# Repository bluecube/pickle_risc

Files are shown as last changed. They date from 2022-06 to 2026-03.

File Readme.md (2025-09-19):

# Pickle RISC 16bit CPU

... so I would like to build a computer, this time a little closer to "from scratch".

## Goals
- Fun!
- Aiming for a poorly defined balance between "easy to build" and "not too slow"
- Can run a multitasking OS
- Serve web site about itself (like Magic-1 does)
- Serial console interface
- Run at ~2MHz clock
    - 4MHz as a stretch goal :)
- Most instruction single cycle
- Probably RPi as a peripherial device, emulating a [GPU](notes/graphics.md), network card, storage, serial terminal...

## State
- Instruction set
    - Kind of done, still being tweaked to match the HW limitations and to improve proramming experience
- HW design
    - Slightly more than a fuzzy idea of how stuff should should go together
    - The block diagram shows most of the general idea
    - There is a [design document](design.md) that contains some (incomplete) information
- SW
    - Skeleton of a toolchain written in Rust ([toolchain-rs/](toolchain-rs/))
    - [Lisp](notes/lisp.md) interpreter is planned as a shell
        - Probably loosely based on [Make a Lisp](https://github.com/kanaka/mal/blob/master/process/guide.md)
        - Compiler as a stretch goal

## Links
### Inspiration
- Magic-1: http://www.homebrewcpu.com/
    - Showed me that there is so much magic in this topic.
    - I would like my machine to look like Magic-1 and do the stuff that Magic-1 does.
- Ben Eater's breadboard computer: https://www.youtube.com/playlist?list=PLowKtXNTBypGqImE405J2565dvjafglHU
    - Gave me the idea that I could actually build something like this.
- James Sharman's JAM-1: https://www.youtube.com/c/weirdboyjim/videos
    - Different goals, but just plain awesome :)

### Instruction set
- ARM Thumb Instruction set
- AVR instruction set

### Peripherials
- Interfacing SDHC card to 6502: https://github.com/gfoot/sdcard6502

### The rest
- MUPS/16, a nice 16bit CPU with similar goals/design: http://mups16.net/pages/overview.html#overview
- RISC-V: https://riscv.org/wp-content/uploads/2017/05/riscv-spec-v2.2.pdf
- Simple almost C-like language: https://incoherency.co.uk/blog/stories/slang.html
- Logisim evolution
- Nandgame ALU https://nandgame.com/
    > The ALU (Arithmetic/Logic Unit) performs one or more operations on two input values X and Y.
    >
    > The six flags select what operations to perform. Each flag trigger an operation when the flag is 1:
    > zx	Use 0 for X
    > nx	Invert X
    > zy	Use 0 for Y
    > ny	Invert Y
    > f	selects an operation:
    > 0: output is X AND Y
    > 1: output is X + Y
    > no	Invert output
    >
    > The flags can be combined and the specified order is significant.
    >
    > For example, if both zx and nx is 1, then X is inverted 0.

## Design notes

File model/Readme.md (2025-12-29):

# Board-level model

The goal of this model is to simulate individual boards.
This is done primarily as a sort of an executable spec for the
kicad schematic designs, but also to simulate (either individual boards, or later full CPU).
This code is not intended to be synthesized.

Also the SystemVerilog module will likely be later used as a source for microcode ROMs.

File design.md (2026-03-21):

# Pickle RISC 16bit CPU

This document contains notes about the hardware design that didn't fit anywhere else.
As usual this is incomplete and slightly outdated.

## Basic design
- 16bit
- Microcoded
- Most instructions take only single clock cycle
    - Instructions with memory access take two
- word addressable memory only!
    - 8bit access emulated in SW, helper instructions
      - `pack` (build word from bytes)
      - `bcmp` (byte-wise compare)
      - `shr8` (shift right by 8 bits)
- 15 general purpose registers R1-R15
- r0 is hardware zero register
- Two stage pipeline
    - Decode, Execute
    - Fetching next instruction is done as part of execute
    - Delay slot after all branch and jump instructions
- Only one status bit: `C`arry
- Control registers (Needs work!)
    - CpuStatus
        - RW
        - Contains:
            - 1b interrupt enabled flag
            - 1b privileged mode flag
                - Controls if privileged instructions are enabled
            - 1b MMU enabled flag
                - If disabled, MMU maps program memory pages 1:1 to frames at the beginning of memory, data pages to frames from in upper half of memory.
            - 6b Context ID
                - Used as a part of virtual page address, equivalent to process ID (with &lt; 64 processes)
    - NextCpuStatus
        - RW
        - Saved CPU status after interrupt
        - New CPU status to be set with ctxsw
    - NextPc
        - RW
        - Saved PC after interrupt
        - New PC to jump to with `ctxsw`
    - IntCause
        - RO
        - Bitmask of interrupt flags (!?!?!?!?)
    - MMUAddr: Virtual page address
        - RW
        - for storing MMU records
        - set during page failure
    - MMUData
        - WO
        - triggers the MMU write at given MMUAddr
    - Display
        - WO
        - Drives a 7-segment display on the front panel
        - 1:1 bit to segment mapping (= no decoder, must be done in SW)
- Separate virtual address spaces for data / code
    - To acces code from a process, the OS must map the memory as data
    - Exception is the ldp (load from program memory) instruction that allows each process to read its program space freely
- Interrupts
- System instructions:
    - `syscall`
        - Causes software interrupt
        - pass immediate value into `IntCause`
            - Quickly distinguish what's necessary in interrupt handler
                - syscall, vs IPC call, vs breakpoint, ...
    - `break`
        - Stop emulator
        - Switch physical CPU into single step mode
            - must be enabled by a physical switch?

## Instruction set weirdness
Compromises have been made :)

- No jumps with immediate values
  - This saves encoding space, but mostly allows us to fetch next instruction after jump without adder delay and without adding another address adder to a different stage.
  - Near jumps can be done in two cycles using `ldpc` (load program counter with offset) and then absolute jump.
  - Tight loops will benefit from preloading jump targets to a register.
- The architecture has something of a "zero page" with faster access
  - Globals within first 256B of memory can be accessed using just `ldi` for address load
    - `ldi addr, 0x17; ld dest, addr + 0`
  - Same for functions -- jumps to first 256 bytes are as fast as relative jumps
    - `ldi addr, 0xa5; jal r0, addr`
- No pop
  - Pop requires two registers to be written.
  - Repeated pops (eg. restoring state after interrupt) can be worked around by batching `ld` with offset followed by a single add. (`ld r1, sp; ld r2,sp+1; ld r3, sp+2; addi sp, sp, 3`)
- `stinc` instead of push
  - This is strictly stronger than push (`push sp, v` = `stinc sp-1, v`)
  - Not sure if arguments other than +-1 are useful, but this instruction is just "we can do it for (almost) free, so why not".
- On wishlist -- slightly weird, but potentially useful:
    - Microcoded multi cycle `memcpy` instruction
      - Probably could run in 2 * N + 1 cycles to copy N words of memory, that's as fast as a dedicated DMA device could run
      - Dedicated DMA would also need to block the CPU (because instruction fetches)
    - Three cycle long atomic swap memory and register instruction
      - Not strictly necessary, because OS can do atomic operations through a syscall, but this would allow us to play with fast futex implementations.

## Microcode ROM
### Incoming signals
(goal is 13 (= 8k ROM), or 15 (= 32k ROM))
- 8 bits from instruction
- 1 bit interrupt pending
- 1 bit kernel mode
- 2 bits condition flags
    - ALU A is zero
    - C
- 2 bits Microcode FSM state

Total 14

### Outgoing control lines
(goal is as small as possible multiple of 8; needs more work)

TODO

- 2 bits Microcode FSM next state

## Memory
- 16 bit-addressable memory (Byte level access emulated in SW)
- Separate data and program segments
- Virtual address format: `CC CCCC S AAAA AA | AA AAAA AAAA`
    - `C` - 6bit context ID (from control register)
    - `S` - segment (0 = data segment, 1 = program segment)
    - `A` - 16bit address
- MMU
    - Built out of two 8k * 8b SRAM ICs
    - Record format: `RWFF FFFF FFFF FFFF`
        - `R` - Read allowed
        - `W` - Write allowed
        - `F` - Frame address (14b)
    - Software page fault handling
        - raises interrupt on access violation
    - 10b page size -> 1kWord = 2kB pages
    - 24b physical address -> 16MWord physical address space
        - 22bit ROM address space
            - 8kWords used (pair of 8k * 8b ROM chips)
        - 22bit device address space
        - 23bit RAM address space
            - max 8MWord = 16MB RAM

## Peripherials wishlist
- UART
- RTC
- Storage
    - SD card using SPI interface?
- [Graphics](notes/graphics.md)
- Network card
    - Probably using the Raspbery PI board (same as with the graphics)
    - W5500 module?
- Hardware multiplier card
    - 16b x 16b -> 32b
    - memory mapped
    - https://www.youtube.com/watch?v=M8dk0JpkrbY

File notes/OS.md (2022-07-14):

# OS
Pickle risc will run a multitasking OS.

## Design

Microkernels are cool.

### Functionatity in kernel
- Scheduler
- IPC
    - Message passing
        - Synchronous
            - Blocking and non-blocking mode
            - Small fixed payload
                - Registers only?
    - Shared memory
        - `sharemem`
            - "Share this page of my memory to that process"
            - returns some sort of ID uniquely identifying the share
        - `mmap` can take the ID from previous step to map the memory

- Memory / paging

### Functionality in servers
- UART driver
- Disk driver
- Filesystem
- Timer
- Networking
- Synchronization & locking

### Semaphores & locking
- Process can only block on message sending / receiving
- Mutex impl -- a little like futex in Linux
    - Atomic variable
        - 0: unlocked
        - 1: locked, noone is waiting
        - >=2 : locked, waiting processes
    - Sends message to synchronization server
        - Block on this
            - How is the lock object identified?
                - the sync server should not need (privileged) access to memory mappings
                - Lock objects carries ID inside?

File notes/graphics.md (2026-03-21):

# Graphics

While the CPU's main focus is to be a multi-user system mainly focused on networking (like Magic-1!),
I'd also like to have at least some fancy graphics.
But I definitely don't want to implement a VGA graphics from discrete logic.

Right now there are two separate options:
1. RPi based GPU, connected over SPI to the CPU memory bus.
2. Network based graphics protocol, display server on a "real" computer.

Both of the options would provide basically the same functionality.

## Goals
- High-ish resolution
- GUI system similar to Windows 3.0 can be built on top of it
- Fast enough for GUI and simple games
    - Even when running over low bandwidth SLIP link

# Design
- 640x480 or 800x600
- 4bpp or 8bpp, 16b palette entries (RGB565)
- Graphics memory
    - 512kB video RAM (TODO: 1MB?)
- Selectable framebuffer offset and row stride
    - Can be used to double buffer and/or scroll the display
- Commands:
    - Upload to graphics memory
    - Blit
        with or without transparent color
    - Draw primitives in graphics memory
        - Axis aligned rectangle
            - filled
            - outlined
        - Line
        - Filled triangle
- Events:
    - Keyboard
    - Mouse
    - Joystick?
- Maybe we could also support sound?
- Emulation details
  - Blitter runs on 2-4MPx/s
  - Emulates scanlines

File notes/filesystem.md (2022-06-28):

# Filesystem notes
These are just quick notes about how I'd like to implement the filesystem,
based only on assumptions on how the storage will work.
No real work has been done on this.

This assumes that we will have something like an SD card connected through SPI.

## Goals
- Simple (will be implemented in assembler)
    - Specifically: Not COW :-)
- Fun!

## Design
- Block size 1kWord = 2kB
    - Matches the MMU page size
- 16b block pointers
- => 128MB max addressable space

### Superblock
- First block of the device
- "PICKLEFS" magic
- Parameters?
- 16b Pointer to first unused block
- 16b Pointer to root directory

### Boot area
- Optional?
- Contiguous range of blocks starting at the second block of the device
- Must have a corresponding directory entry and file header

### Unused blocks
- 16b pointer to next unused block

### Root directory
- `..` entry points to itself
- Otherwise like normal directory

### Directory
- Creation date
    - ?
- Flags
    - ?
- 16b refcount
- List of entries
    - Name
        - Length?
        - Format?
    - 16b pointer to first block of entry (either file header or directory)
- 16b pointer to next block of directory
- Special entry
    - `..` pointing to parent
- Additional directory blocks only contain the entry list and next pointer

### File header
- Creation date
    - ?
- Flags
    - ?
- 16b refcount
- Size in B
    - 32b?
- List of 16b data block pointers
    - Number of valid blocks can be calculated from file size
- 16b pointer to next block of file header
- Additional file header blocks only contain the block pointer list and next pointer

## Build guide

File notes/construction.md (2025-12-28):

# CPU Mechanical & Electrical Construction

- Eurocard (3U, 100x160mm)
- 96 pin connector
- Backplane split into two zones
  - Core zone:
    - CPU internal cards (register decoder, register slices, ALU, instruction decoder, ...).
    - Each backplane slot has potentially different pinout
    - 3D printed keys enforcing correct card placement?
  - Memory / peripherial zone
    - All pinouts identical
- "Tiled" backplane?
  - Individual pieces of backplane connected together using edge connectors
  - To simplify development, make cheaper fails
- Clock
  - Selectable speed main clock (>=10MHz max speed)
    - 20MHz oscillator piped into 74HC193
    - DIP switch controling the frequency
    - Second counter chip for clock assymetry?
  - Single step mode (buttons: Stop, Step, Run)
  - Break function
    - If enabled by a HW switch, goes into single step mode.
    - Interrupt if break signal arrives and break is disabled
  - Sleep mode (clock is ignored until an interrupt arrives)

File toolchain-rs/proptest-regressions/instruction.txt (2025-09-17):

# Seeds for failure cases proptest has generated in the past. It is
# automatically read and these particular cases re-run before any
# novel cases are generated.
#
# It is recommended to check this file in to source control so that
# everyone who runs the test benefits from these saved cases.
cc 9dc10df642abab5001a11f73752e9213c0fbb279a0ac84b5d1df86588d58f470 # shrinks to input = _InstructionWordRoundtripArgs { instr: Add { rd: Reg(u4(0)), ra: Reg(u4(8)), rb: Reg(u4(0)) } }
cc bcaa2e5ca4c8241c8ef2832069ae7a77c72e44657debe7e9c622a8bcb71ae072 # shrinks to input = _InstructionWordRoundtripArgs { instr: Bc { offset: -1 } }
cc d3591c18287fcd63b3d7897a659aaecbf9b31d5293ab9dd24c8d99ab523e4f6f # shrinks to input = _InstructionWordRoundtripArgs { instr: Bnc { offset: 0 } }
cc fd1b72449b7ee29276ebb02a0e1c3fad55f5e9b69171cacf9a00b8df15d9bed2 # shrinks to input = _InstructionWordRoundtripArgs { instr: Addi { rd: Reg(u4(0)), v: 1 } }
cc 28ca0e33b48f58821ffe0bdb45a0052da90d4b49a57a24e807921635d42b3c66 # shrinks to input = _InstructionWordRoundtripArgs { instr: Syscall { val: u4(0) } }
cc 16a8a451fe999dba209733c277c157544f69e01f3e4dd4225c0b32ed40378362 # shrinks to input = _RegBadU16Args { num: 8 }

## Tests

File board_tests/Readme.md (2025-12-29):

# Python tests for boards

Plan here is to have one set of python tests per board, ideally completely testing the behavior.

The tests can then be executed against the [verilog model](../model), or against real hardware
using the board tester (TBD).

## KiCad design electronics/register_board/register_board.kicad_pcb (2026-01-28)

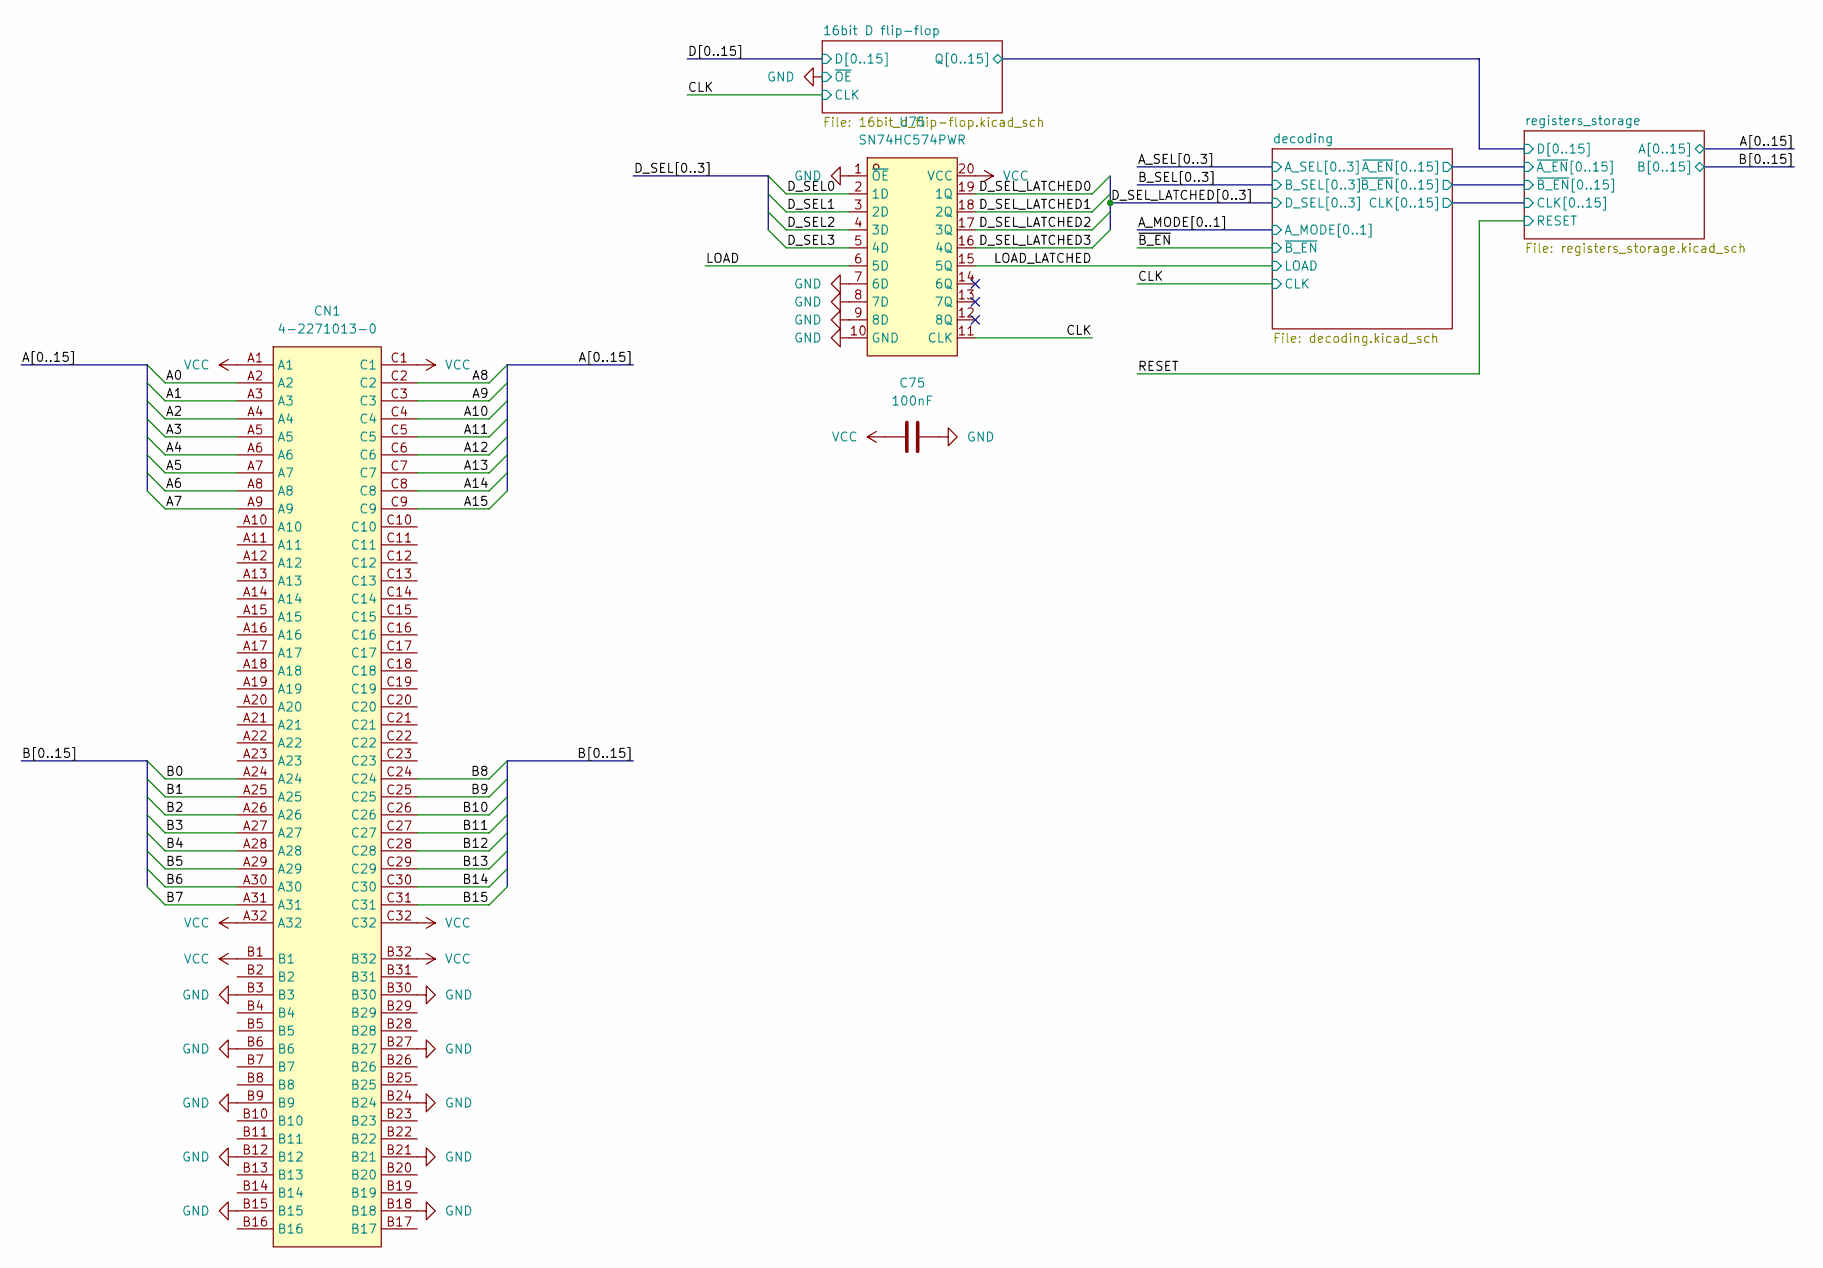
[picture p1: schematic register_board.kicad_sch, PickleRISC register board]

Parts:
C75: 100nF; C_0603_1608Metric
CN1: 4-2271013-0; CONN-TH_96P-P2.54_4-2271013-0; LCSC Part C442617
U75: SN74HC574PWR; TSSOP-20_L6.5-W4.4-P0.65-LS6.4-BL; LCSC Part C132111

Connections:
/A0: CN1.A2; also elsewhere on the board
/A1: CN1.A3; also elsewhere on the board
/A2: CN1.A4; also elsewhere on the board
/A3: CN1.A5; also elsewhere on the board
/A4: CN1.A6; also elsewhere on the board
/A5: CN1.A7; also elsewhere on the board
/A6: CN1.A8; also elsewhere on the board
/A7: CN1.A9; also elsewhere on the board
/A8: CN1.C2; also elsewhere on the board
/A9: CN1.C3; also elsewhere on the board
/A10: CN1.C4; also elsewhere on the board
/A11: CN1.C5; also elsewhere on the board
/A12: CN1.C6; also elsewhere on the board
/A13: CN1.C7; also elsewhere on the board
/A14: CN1.C8; also elsewhere on the board
/A15: CN1.C9; also elsewhere on the board
/B0: CN1.A24; also elsewhere on the board
/B1: CN1.A25; also elsewhere on the board
/B2: CN1.A26; also elsewhere on the board
/B3: CN1.A27; also elsewhere on the board
/B4: CN1.A28; also elsewhere on the board
/B5: CN1.A29; also elsewhere on the board
/B6: CN1.A30; also elsewhere on the board
/B7: CN1.A31; also elsewhere on the board
/B8: CN1.C24; also elsewhere on the board
/B9: CN1.C25; also elsewhere on the board
/B10: CN1.C26; also elsewhere on the board
/B11: CN1.C27; also elsewhere on the board
/B12: CN1.C28; also elsewhere on the board
/B13: CN1.C29; also elsewhere on the board
/B14: CN1.C30; also elsewhere on the board
/B15: CN1.C31; also elsewhere on the board
/CLK: U75.11 (CLK); also elsewhere on the board
/D_SEL0: U75.2 (1D)
/D_SEL1: U75.3 (2D)
/D_SEL2: U75.4 (3D)
/D_SEL3: U75.5 (4D)
/D_SEL_LATCHED0: U75.19 (1Q); also elsewhere on the board
/D_SEL_LATCHED1: U75.18 (2Q); also elsewhere on the board
/D_SEL_LATCHED2: U75.17 (3Q); also elsewhere on the board
/D_SEL_LATCHED3: U75.16 (4Q); also elsewhere on the board
/LOAD: U75.6 (5D)
/LOAD_LATCHED: U75.15 (5Q); also elsewhere on the board
GND: C75.2, CN1.B3, CN1.B6, CN1.B9, CN1.B12, CN1.B15, CN1.B18, CN1.B21, CN1.B24, CN1.B27, CN1.B30, U75.1 (~OE), U75.7 (6D), U75.8 (7D), U75.9 (8D), U75.10 (GND); also elsewhere on the board
VCC: C75.1, CN1.A1, CN1.A32, CN1.B1, CN1.B32, CN1.C1, CN1.C32, U75.20 (VCC); also elsewhere on the board

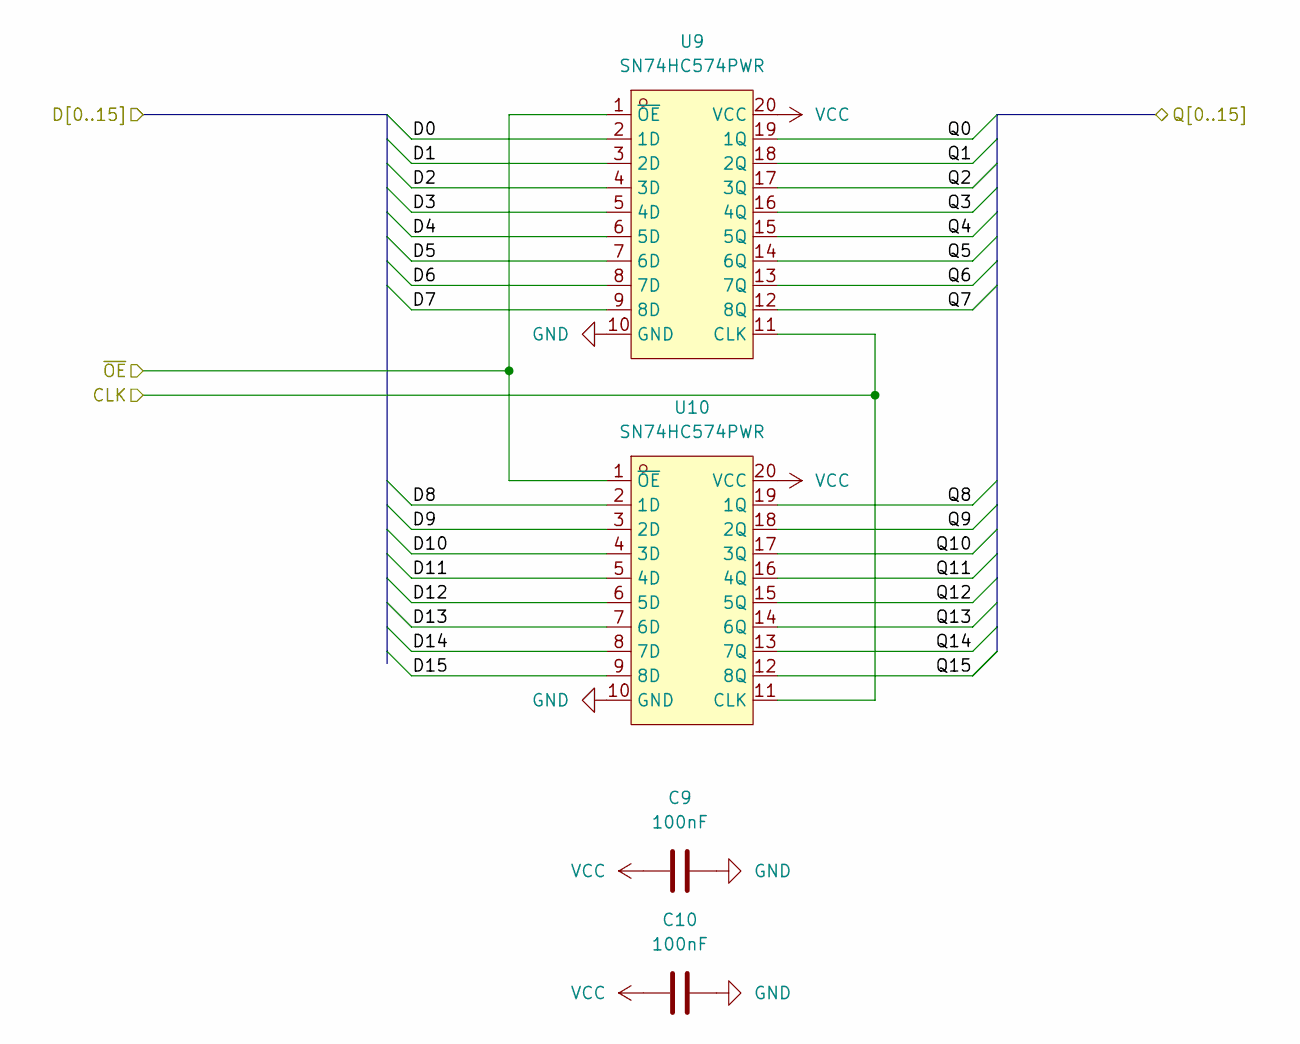
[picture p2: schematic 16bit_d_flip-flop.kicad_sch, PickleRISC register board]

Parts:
C9, C10: 100nF; C_0603_1608Metric
U9, U10: SN74HC574PWR; TSSOP-20_L6.5-W4.4-P0.65-LS6.4-BL; LCSC Part C132111

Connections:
/CLK: U9.11 (CLK), U10.11 (CLK); also elsewhere on the board
/D0: U9.2 (1D)
/D1: U9.3 (2D)
/D2: U9.4 (3D)
/D3: U9.5 (4D)
/D4: U9.6 (5D)
/D5: U9.7 (6D)
/D6: U9.8 (7D)
/D7: U9.9 (8D)
/D8: U10.2 (1D)
/D9: U10.3 (2D)
/D10: U10.4 (3D)
/D11: U10.5 (4D)
/D12: U10.6 (5D)
/D13: U10.7 (6D)
/D14: U10.8 (7D)
/D15: U10.9 (8D)
/registers_storage/D0: U9.19 (1Q); also elsewhere on the board
/registers_storage/D1: U9.18 (2Q); also elsewhere on the board
/registers_storage/D2: U9.17 (3Q); also elsewhere on the board
/registers_storage/D3: U9.16 (4Q); also elsewhere on the board
/registers_storage/D4: U9.15 (5Q); also elsewhere on the board
/registers_storage/D5: U9.14 (6Q); also elsewhere on the board
/registers_storage/D6: U9.13 (7Q); also elsewhere on the board
/registers_storage/D7: U9.12 (8Q); also elsewhere on the board
/registers_storage/D8: U10.19 (1Q); also elsewhere on the board
/registers_storage/D9: U10.18 (2Q); also elsewhere on the board
/registers_storage/D10: U10.17 (3Q); also elsewhere on the board
/registers_storage/D11: U10.16 (4Q); also elsewhere on the board
/registers_storage/D12: U10.15 (5Q); also elsewhere on the board
/registers_storage/D13: U10.14 (6Q); also elsewhere on the board
/registers_storage/D14: U10.13 (7Q); also elsewhere on the board
/registers_storage/D15: U10.12 (8Q); also elsewhere on the board
GND: C9.2, C10.2, U9.1 (~OE), U9.10 (GND), U10.1 (~OE), U10.10 (GND); also elsewhere on the board
VCC: C9.1, C10.1, U9.20 (VCC), U10.20 (VCC); also elsewhere on the board

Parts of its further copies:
C15, C16, C17, C18, C19, C20, C21, C22, C23, C24, C25, C26, C27, C28, C29, C30, C31, C32, C33, C34, C35, C36, C37, C38, C39, C40, C41, C42, C43, C44, C45, C46, C47, C48, C49, C50, C51, C52, C53, C54, C55, C56, C57, C58, C59, C60, C61, C62, C63, C64, C65, C66, C67, C68, C69, C70, C71, C72, C73, C74: 100nF; C_0603_1608Metric
U15, U16, U17, U18, U19, U20, U21, U22, U23, U24, U25, U26, U27, U28, U29, U30, U31, U32, U33, U34, U35, U36, U37, U38, U39, U40, U41, U42, U43, U44, U45, U46, U47, U48, U49, U50, U51, U52, U53, U54, U55, U56, U57, U58, U59, U60, U61, U62, U63, U64, U65, U66, U67, U68, U69, U70, U71, U72, U73, U74: SN74HC574PWR; TSSOP-20_L6.5-W4.4-P0.65-LS6.4-BL; LCSC Part C132111

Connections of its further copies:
/A0: U15.19 (1Q), U19.19 (1Q), U23.19 (1Q), U27.19 (1Q), U31.19 (1Q), U35.19 (1Q), U39.19 (1Q), U43.19 (1Q), U47.19 (1Q), U51.19 (1Q), U55.19 (1Q), U59.19 (1Q), U63.19 (1Q), U67.19 (1Q), U71.19 (1Q); also elsewhere on the board
/A1: U15.18 (2Q), U19.18 (2Q), U23.18 (2Q), U27.18 (2Q), U31.18 (2Q), U35.18 (2Q), U39.18 (2Q), U43.18 (2Q), U47.18 (2Q), U51.18 (2Q), U55.18 (2Q), U59.18 (2Q), U63.18 (2Q), U67.18 (2Q), U71.18 (2Q); also elsewhere on the board
/A2: U15.17 (3Q), U19.17 (3Q), U23.17 (3Q), U27.17 (3Q), U31.17 (3Q), U35.17 (3Q), U39.17 (3Q), U43.17 (3Q), U47.17 (3Q), U51.17 (3Q), U55.17 (3Q), U59.17 (3Q), U63.17 (3Q), U67.17 (3Q), U71.17 (3Q); also elsewhere on the board
/A3: U15.16 (4Q), U19.16 (4Q), U23.16 (4Q), U27.16 (4Q), U31.16 (4Q), U35.16 (4Q), U39.16 (4Q), U43.16 (4Q), U47.16 (4Q), U51.16 (4Q), U55.16 (4Q), U59.16 (4Q), U63.16 (4Q), U67.16 (4Q), U71.16 (4Q); also elsewhere on the board
/A4: U15.15 (5Q), U19.15 (5Q), U23.15 (5Q), U27.15 (5Q), U31.15 (5Q), U35.15 (5Q), U39.15 (5Q), U43.15 (5Q), U47.15 (5Q), U51.15 (5Q), U55.15 (5Q), U59.15 (5Q), U63.15 (5Q), U67.15 (5Q), U71.15 (5Q); also elsewhere on the board
/A5: U15.14 (6Q), U19.14 (6Q), U23.14 (6Q), U27.14 (6Q), U31.14 (6Q), U35.14 (6Q), U39.14 (6Q), U43.14 (6Q), U47.14 (6Q), U51.14 (6Q), U55.14 (6Q), U59.14 (6Q), U63.14 (6Q), U67.14 (6Q), U71.14 (6Q); also elsewhere on the board
/A6: U15.13 (7Q), U19.13 (7Q), U23.13 (7Q), U27.13 (7Q), U31.13 (7Q), U35.13 (7Q), U39.13 (7Q), U43.13 (7Q), U47.13 (7Q), U51.13 (7Q), U55.13 (7Q), U59.13 (7Q), U63.13 (7Q), U67.13 (7Q), U71.13 (7Q); also elsewhere on the board
/A7: U15.12 (8Q), U19.12 (8Q), U23.12 (8Q), U27.12 (8Q), U31.12 (8Q), U35.12 (8Q), U39.12 (8Q), U43.12 (8Q), U47.12 (8Q), U51.12 (8Q), U55.12 (8Q), U59.12 (8Q), U63.12 (8Q), U67.12 (8Q), U71.12 (8Q); also elsewhere on the board
/A8: U16.19 (1Q), U20.19 (1Q), U24.19 (1Q), U28.19 (1Q), U32.19 (1Q), U36.19 (1Q), U40.19 (1Q), U44.19 (1Q), U48.19 (1Q), U52.19 (1Q), U56.19 (1Q), U60.19 (1Q), U64.19 (1Q), U68.19 (1Q), U72.19 (1Q); also elsewhere on the board
/A9: U16.18 (2Q), U20.18 (2Q), U24.18 (2Q), U28.18 (2Q), U32.18 (2Q), U36.18 (2Q), U40.18 (2Q), U44.18 (2Q), U48.18 (2Q), U52.18 (2Q), U56.18 (2Q), U60.18 (2Q), U64.18 (2Q), U68.18 (2Q), U72.18 (2Q); also elsewhere on the board
/A10: U16.17 (3Q), U20.17 (3Q), U24.17 (3Q), U28.17 (3Q), U32.17 (3Q), U36.17 (3Q), U40.17 (3Q), U44.17 (3Q), U48.17 (3Q), U52.17 (3Q), U56.17 (3Q), U60.17 (3Q), U64.17 (3Q), U68.17 (3Q), U72.17 (3Q); also elsewhere on the board
/A11: U16.16 (4Q), U20.16 (4Q), U24.16 (4Q), U28.16 (4Q), U32.16 (4Q), U36.16 (4Q), U40.16 (4Q), U44.16 (4Q), U48.16 (4Q), U52.16 (4Q), U56.16 (4Q), U60.16 (4Q), U64.16 (4Q), U68.16 (4Q), U72.16 (4Q); also elsewhere on the board
/A12: U16.15 (5Q), U20.15 (5Q), U24.15 (5Q), U28.15 (5Q), U32.15 (5Q), U36.15 (5Q), U40.15 (5Q), U44.15 (5Q), U48.15 (5Q), U52.15 (5Q), U56.15 (5Q), U60.15 (5Q), U64.15 (5Q), U68.15 (5Q), U72.15 (5Q); also elsewhere on the board
/A13: U16.14 (6Q), U20.14 (6Q), U24.14 (6Q), U28.14 (6Q), U32.14 (6Q), U36.14 (6Q), U40.14 (6Q), U44.14 (6Q), U48.14 (6Q), U52.14 (6Q), U56.14 (6Q), U60.14 (6Q), U64.14 (6Q), U68.14 (6Q), U72.14 (6Q); also elsewhere on the board
/A14: U16.13 (7Q), U20.13 (7Q), U24.13 (7Q), U28.13 (7Q), U32.13 (7Q), U36.13 (7Q), U40.13 (7Q), U44.13 (7Q), U48.13 (7Q), U52.13 (7Q), U56.13 (7Q), U60.13 (7Q), U64.13 (7Q), U68.13 (7Q), U72.13 (7Q); also elsewhere on the board
/A15: U16.12 (8Q), U20.12 (8Q), U24.12 (8Q), U28.12 (8Q), U32.12 (8Q), U36.12 (8Q), U40.12 (8Q), U44.12 (8Q), U48.12 (8Q), U52.12 (8Q), U56.12 (8Q), U60.12 (8Q), U64.12 (8Q), U68.12 (8Q), U72.12 (8Q); also elsewhere on the board
/B0: U17.19 (1Q), U21.19 (1Q), U25.19 (1Q), U29.19 (1Q), U33.19 (1Q), U37.19 (1Q), U41.19 (1Q), U45.19 (1Q), U49.19 (1Q), U53.19 (1Q), U57.19 (1Q), U61.19 (1Q), U65.19 (1Q), U69.19 (1Q), U73.19 (1Q); also elsewhere on the board
/B1: U17.18 (2Q), U21.18 (2Q), U25.18 (2Q), U29.18 (2Q), U33.18 (2Q), U37.18 (2Q), U41.18 (2Q), U45.18 (2Q), U49.18 (2Q), U53.18 (2Q), U57.18 (2Q), U61.18 (2Q), U65.18 (2Q), U69.18 (2Q), U73.18 (2Q); also elsewhere on the board
/B2: U17.17 (3Q), U21.17 (3Q), U25.17 (3Q), U29.17 (3Q), U33.17 (3Q), U37.17 (3Q), U41.17 (3Q), U45.17 (3Q), U49.17 (3Q), U53.17 (3Q), U57.17 (3Q), U61.17 (3Q), U65.17 (3Q), U69.17 (3Q), U73.17 (3Q); also elsewhere on the board
/B3: U17.16 (4Q), U21.16 (4Q), U25.16 (4Q), U29.16 (4Q), U33.16 (4Q), U37.16 (4Q), U41.16 (4Q), U45.16 (4Q), U49.16 (4Q), U53.16 (4Q), U57.16 (4Q), U61.16 (4Q), U65.16 (4Q), U69.16 (4Q), U73.16 (4Q); also elsewhere on the board
/B4: U17.15 (5Q), U21.15 (5Q), U25.15 (5Q), U29.15 (5Q), U33.15 (5Q), U37.15 (5Q), U41.15 (5Q), U45.15 (5Q), U49.15 (5Q), U53.15 (5Q), U57.15 (5Q), U61.15 (5Q), U65.15 (5Q), U69.15 (5Q), U73.15 (5Q); also elsewhere on the board
/B5: U17.14 (6Q), U21.14 (6Q), U25.14 (6Q), U29.14 (6Q), U33.14 (6Q), U37.14 (6Q), U41.14 (6Q), U45.14 (6Q), U49.14 (6Q), U53.14 (6Q), U57.14 (6Q), U61.14 (6Q), U65.14 (6Q), U69.14 (6Q), U73.14 (6Q); also elsewhere on the board
/B6: U17.13 (7Q), U21.13 (7Q), U25.13 (7Q), U29.13 (7Q), U33.13 (7Q), U37.13 (7Q), U41.13 (7Q), U45.13 (7Q), U49.13 (7Q), U53.13 (7Q), U57.13 (7Q), U61.13 (7Q), U65.13 (7Q), U69.13 (7Q), U73.13 (7Q); also elsewhere on the board
/B7: U17.12 (8Q), U21.12 (8Q), U25.12 (8Q), U29.12 (8Q), U33.12 (8Q), U37.12 (8Q), U41.12 (8Q), U45.12 (8Q), U49.12 (8Q), U53.12 (8Q), U57.12 (8Q), U61.12 (8Q), U65.12 (8Q), U69.12 (8Q), U73.12 (8Q); also elsewhere on the board
/B8: U18.19 (1Q), U22.19 (1Q), U26.19 (1Q), U30.19 (1Q), U34.19 (1Q), U38.19 (1Q), U42.19 (1Q), U46.19 (1Q), U50.19 (1Q), U54.19 (1Q), U58.19 (1Q), U62.19 (1Q), U66.19 (1Q), U70.19 (1Q), U74.19 (1Q); also elsewhere on the board
/B9: U18.18 (2Q), U22.18 (2Q), U26.18 (2Q), U30.18 (2Q), U34.18 (2Q), U38.18 (2Q), U42.18 (2Q), U46.18 (2Q), U50.18 (2Q), U54.18 (2Q), U58.18 (2Q), U62.18 (2Q), U66.18 (2Q), U70.18 (2Q), U74.18 (2Q); also elsewhere on the board
/B10: U18.17 (3Q), U22.17 (3Q), U26.17 (3Q), U30.17 (3Q), U34.17 (3Q), U38.17 (3Q), U42.17 (3Q), U46.17 (3Q), U50.17 (3Q), U54.17 (3Q), U58.17 (3Q), U62.17 (3Q), U66.17 (3Q), U70.17 (3Q), U74.17 (3Q); also elsewhere on the board
/B11: U18.16 (4Q), U22.16 (4Q), U26.16 (4Q), U30.16 (4Q), U34.16 (4Q), U38.16 (4Q), U42.16 (4Q), U46.16 (4Q), U50.16 (4Q), U54.16 (4Q), U58.16 (4Q), U62.16 (4Q), U66.16 (4Q), U70.16 (4Q), U74.16 (4Q); also elsewhere on the board
/B12: U18.15 (5Q), U22.15 (5Q), U26.15 (5Q), U30.15 (5Q), U34.15 (5Q), U38.15 (5Q), U42.15 (5Q), U46.15 (5Q), U50.15 (5Q), U54.15 (5Q), U58.15 (5Q), U62.15 (5Q), U66.15 (5Q), U70.15 (5Q), U74.15 (5Q); also elsewhere on the board
/B13: U18.14 (6Q), U22.14 (6Q), U26.14 (6Q), U30.14 (6Q), U34.14 (6Q), U38.14 (6Q), U42.14 (6Q), U46.14 (6Q), U50.14 (6Q), U54.14 (6Q), U58.14 (6Q), U62.14 (6Q), U66.14 (6Q), U70.14 (6Q), U74.14 (6Q); also elsewhere on the board
/B14: U18.13 (7Q), U22.13 (7Q), U26.13 (7Q), U30.13 (7Q), U34.13 (7Q), U38.13 (7Q), U42.13 (7Q), U46.13 (7Q), U50.13 (7Q), U54.13 (7Q), U58.13 (7Q), U62.13 (7Q), U66.13 (7Q), U70.13 (7Q), U74.13 (7Q); also elsewhere on the board
/B15: U18.12 (8Q), U22.12 (8Q), U26.12 (8Q), U30.12 (8Q), U34.12 (8Q), U38.12 (8Q), U42.12 (8Q), U46.12 (8Q), U50.12 (8Q), U54.12 (8Q), U58.12 (8Q), U62.12 (8Q), U66.12 (8Q), U70.12 (8Q), U74.12 (8Q); also elsewhere on the board
/decoding/CLK1: U15.11 (CLK), U16.11 (CLK), U17.11 (CLK), U18.11 (CLK); also elsewhere on the board
/decoding/CLK2: U19.11 (CLK), U20.11 (CLK), U21.11 (CLK), U22.11 (CLK); also elsewhere on the board
/decoding/CLK3: U23.11 (CLK), U24.11 (CLK), U25.11 (CLK), U26.11 (CLK); also elsewhere on the board
/decoding/CLK4: U27.11 (CLK), U28.11 (CLK), U29.11 (CLK), U30.11 (CLK); also elsewhere on the board
/decoding/CLK5: U31.11 (CLK), U32.11 (CLK), U33.11 (CLK), U34.11 (CLK); also elsewhere on the board
/decoding/CLK6: U35.11 (CLK), U36.11 (CLK), U37.11 (CLK), U38.11 (CLK); also elsewhere on the board
/decoding/CLK7: U39.11 (CLK), U40.11 (CLK), U41.11 (CLK), U42.11 (CLK); also elsewhere on the board
/decoding/CLK8: U43.11 (CLK), U44.11 (CLK), U45.11 (CLK), U46.11 (CLK); also elsewhere on the board
/decoding/CLK9: U47.11 (CLK), U48.11 (CLK), U49.11 (CLK), U50.11 (CLK); also elsewhere on the board
/decoding/CLK10: U51.11 (CLK), U52.11 (CLK), U53.11 (CLK), U54.11 (CLK); also elsewhere on the board
/decoding/CLK11: U55.11 (CLK), U56.11 (CLK), U57.11 (CLK), U58.11 (CLK); also elsewhere on the board
/decoding/CLK12: U59.11 (CLK), U60.11 (CLK), U61.11 (CLK), U62.11 (CLK); also elsewhere on the board
/decoding/CLK13: U63.11 (CLK), U64.11 (CLK), U65.11 (CLK), U66.11 (CLK); also elsewhere on the board
/decoding/CLK14: U67.11 (CLK), U68.11 (CLK), U69.11 (CLK), U70.11 (CLK); also elsewhere on the board
/decoding/CLK15: U71.11 (CLK), U72.11 (CLK), U73.11 (CLK), U74.11 (CLK); also elsewhere on the board
/decoding/~A_EN1: U15.1 (~OE), U16.1 (~OE); also elsewhere on the board
/decoding/~A_EN2: U19.1 (~OE), U20.1 (~OE); also elsewhere on the board
/decoding/~A_EN3: U23.1 (~OE), U24.1 (~OE); also elsewhere on the board
/decoding/~A_EN4: U27.1 (~OE), U28.1 (~OE); also elsewhere on the board
/decoding/~A_EN5: U31.1 (~OE), U32.1 (~OE); also elsewhere on the board
/decoding/~A_EN6: U35.1 (~OE), U36.1 (~OE); also elsewhere on the board
/decoding/~A_EN7: U39.1 (~OE), U40.1 (~OE); also elsewhere on the board
/decoding/~A_EN8: U43.1 (~OE), U44.1 (~OE); also elsewhere on the board
/decoding/~A_EN9: U47.1 (~OE), U48.1 (~OE); also elsewhere on the board
/decoding/~A_EN10: U51.1 (~OE), U52.1 (~OE); also elsewhere on the board
/decoding/~A_EN11: U55.1 (~OE), U56.1 (~OE); also elsewhere on the board
/decoding/~A_EN12: U59.1 (~OE), U60.1 (~OE); also elsewhere on the board
/decoding/~A_EN13: U63.1 (~OE), U64.1 (~OE); also elsewhere on the board
/decoding/~A_EN14: U67.1 (~OE), U68.1 (~OE); also elsewhere on the board
/decoding/~A_EN15: U71.1 (~OE), U72.1 (~OE); also elsewhere on the board
/decoding/~B_EN1: U17.1 (~OE), U18.1 (~OE); also elsewhere on the board
/decoding/~B_EN2: U21.1 (~OE), U22.1 (~OE); also elsewhere on the board
/decoding/~B_EN3: U25.1 (~OE), U26.1 (~OE); also elsewhere on the board
/decoding/~B_EN4: U29.1 (~OE), U30.1 (~OE); also elsewhere on the board
/decoding/~B_EN5: U33.1 (~OE), U34.1 (~OE); also elsewhere on the board
/decoding/~B_EN6: U37.1 (~OE), U38.1 (~OE); also elsewhere on the board
/decoding/~B_EN7: U41.1 (~OE), U42.1 (~OE); also elsewhere on the board
/decoding/~B_EN8: U45.1 (~OE), U46.1 (~OE); also elsewhere on the board
/decoding/~B_EN9: U49.1 (~OE), U50.1 (~OE); also elsewhere on the board
/decoding/~B_EN10: U53.1 (~OE), U54.1 (~OE); also elsewhere on the board
/decoding/~B_EN11: U57.1 (~OE), U58.1 (~OE); also elsewhere on the board
/decoding/~B_EN12: U61.1 (~OE), U62.1 (~OE); also elsewhere on the board
/decoding/~B_EN13: U65.1 (~OE), U66.1 (~OE); also elsewhere on the board
/decoding/~B_EN14: U69.1 (~OE), U70.1 (~OE); also elsewhere on the board
/decoding/~B_EN15: U73.1 (~OE), U74.1 (~OE); also elsewhere on the board
/registers_storage/D0: U15.2 (1D), U17.2 (1D), U19.2 (1D), U21.2 (1D), U23.2 (1D), U25.2 (1D), U27.2 (1D), U29.2 (1D), U31.2 (1D), U33.2 (1D), U35.2 (1D), U37.2 (1D), U39.2 (1D), U41.2 (1D), U43.2 (1D), U45.2 (1D), U47.2 (1D), U49.2 (1D), U51.2 (1D), U53.2 (1D), U55.2 (1D), U57.2 (1D), U59.2 (1D), U61.2 (1D), U63.2 (1D), U65.2 (1D), U67.2 (1D), U69.2 (1D), U71.2 (1D), U73.2 (1D); also elsewhere on the board
/registers_storage/D1: U15.3 (2D), U17.3 (2D), U19.3 (2D), U21.3 (2D), U23.3 (2D), U25.3 (2D), U27.3 (2D), U29.3 (2D), U31.3 (2D), U33.3 (2D), U35.3 (2D), U37.3 (2D), U39.3 (2D), U41.3 (2D), U43.3 (2D), U45.3 (2D), U47.3 (2D), U49.3 (2D), U51.3 (2D), U53.3 (2D), U55.3 (2D), U57.3 (2D), U59.3 (2D), U61.3 (2D), U63.3 (2D), U65.3 (2D), U67.3 (2D), U69.3 (2D), U71.3 (2D), U73.3 (2D); also elsewhere on the board
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

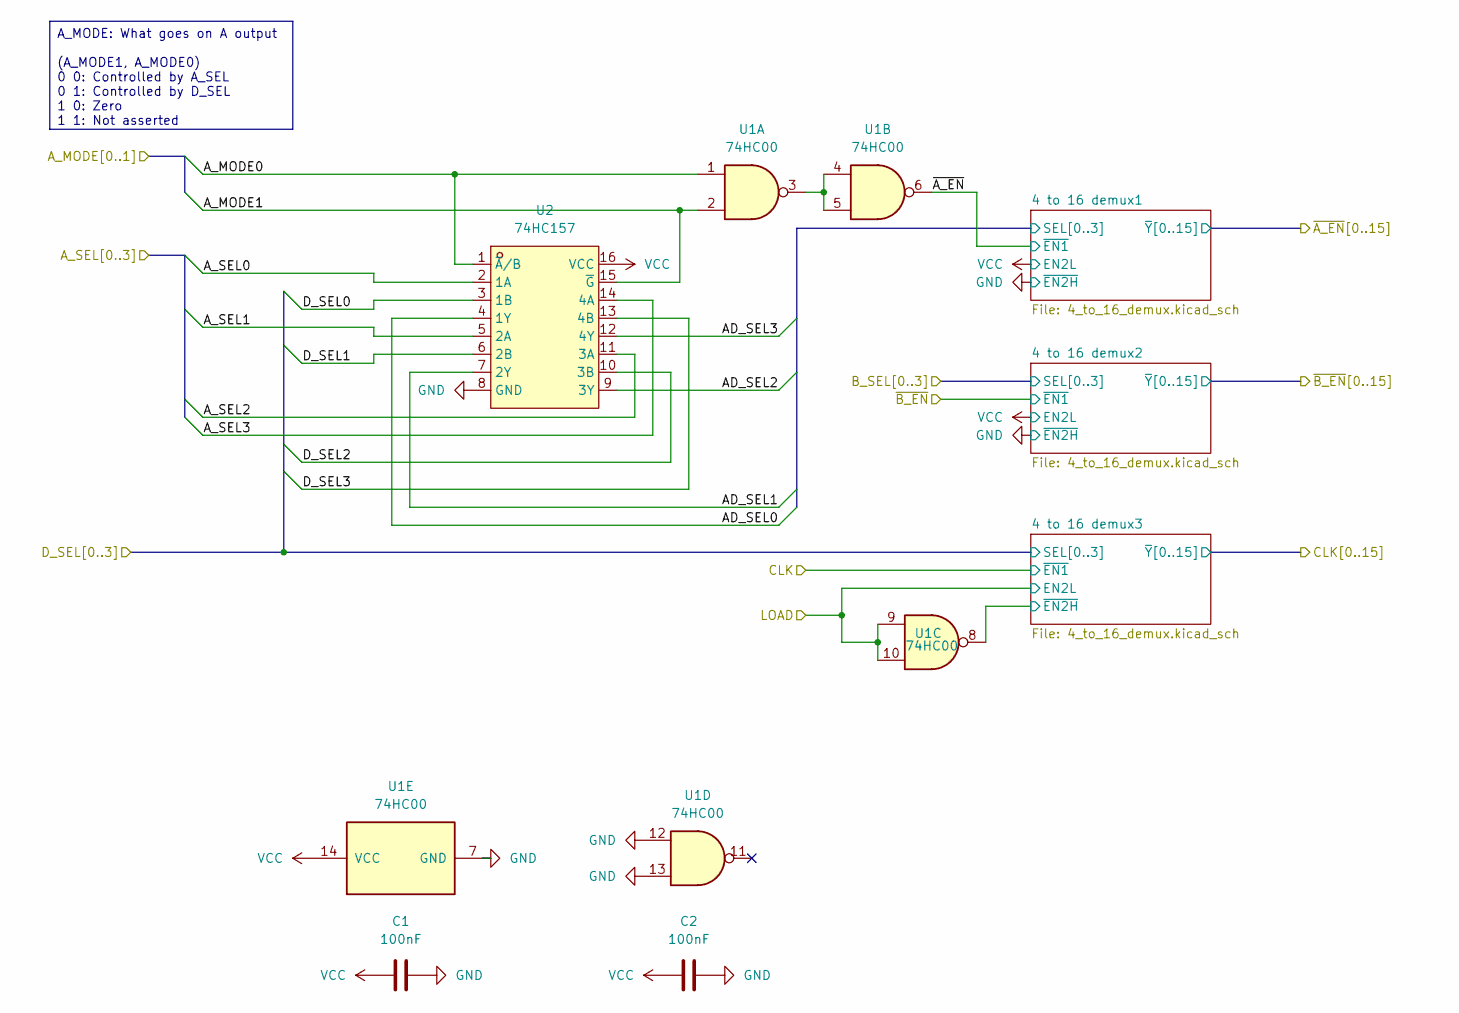
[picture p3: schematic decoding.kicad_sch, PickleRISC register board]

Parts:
C1, C2: 100nF; C_0603_1608Metric
U1: 74HC00; TSSOP-14_L5.0-W4.4-P0.65-LS6.4-BL
U2: 74HC157; TSSOP-16_L5.0-W4.4-P0.65-LS6.4-BL; LCSC Part C408973

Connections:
/A_MODE0: U1.1, U2.1 (~A/B)
/A_MODE1: U1.2, U2.15 (~G)
/A_SEL0: U2.2 (1A)
/A_SEL1: U2.5 (2A)
/A_SEL2: U2.11 (3A)
/A_SEL3: U2.14 (4A)
/D_SEL_LATCHED0: U2.3 (1B); also elsewhere on the board
/D_SEL_LATCHED1: U2.6 (2B); also elsewhere on the board
/D_SEL_LATCHED2: U2.10 (3B); also elsewhere on the board
/D_SEL_LATCHED3: U2.13 (4B); also elsewhere on the board
/LOAD_LATCHED: U1.9, U1.10; also elsewhere on the board
/decoding/4 to 16 demux3/~EN2H: U1.8; also elsewhere on the board
/decoding/AD_SEL0: U2.4 (1Y)
/decoding/AD_SEL1: U2.7 (2Y)
/decoding/AD_SEL2: U2.9 (3Y)
/decoding/AD_SEL3: U2.12 (4Y)
/decoding/~A_EN: U1.6; also elsewhere on the board
GND: C1.2, C2.2, U1.7 (GND), U1.12, U1.13, U2.8 (GND); also elsewhere on the board
unnamed: U1.3, U1.4, U1.5
VCC: C1.1, C2.1, U1.14 (VCC), U2.16 (VCC); also elsewhere on the board

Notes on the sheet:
A_MODE: What goes on A output (A_MODE1, A_MODE0) 0 0: Controlled by A_SEL 0 1: Controlled by D_SEL 1 0: Zero 1 1: Not asserted

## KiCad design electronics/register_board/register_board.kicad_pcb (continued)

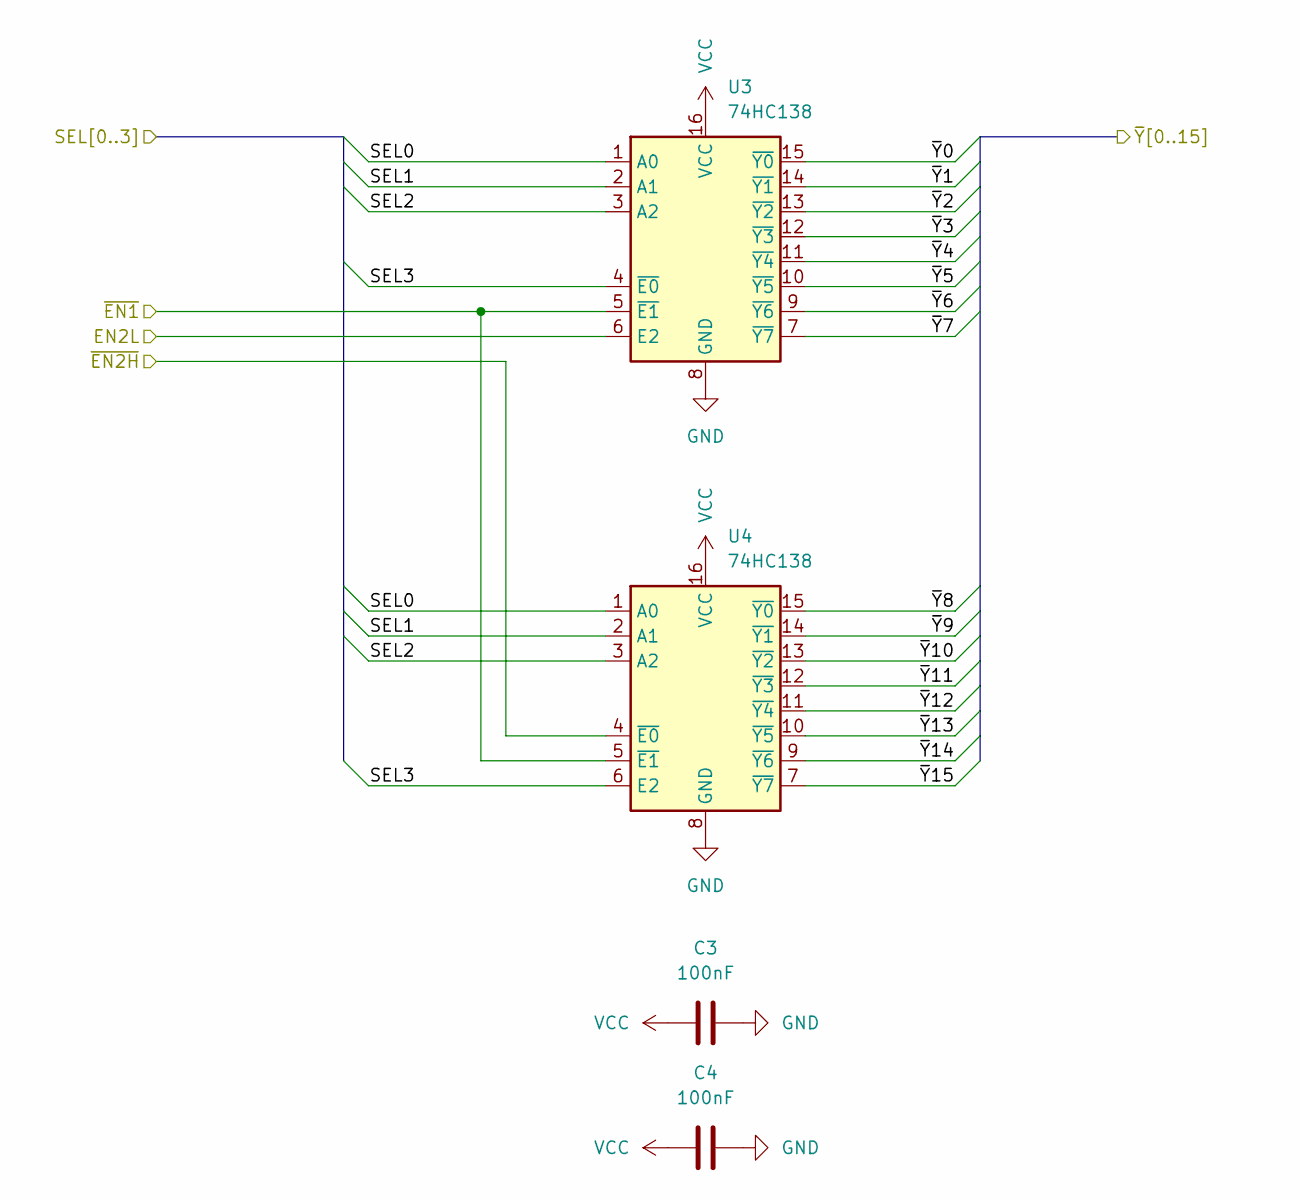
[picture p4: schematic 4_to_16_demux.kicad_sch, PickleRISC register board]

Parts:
C3, C4: 100nF; C_0603_1608Metric
U3, U4: 74HC138; TSSOP-16_L5.0-W4.4-P0.65-LS6.4-BL

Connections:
/decoding/4 to 16 demux1/SEL0: U3.1 (A0), U4.1 (A0)
/decoding/4 to 16 demux1/SEL1: U3.2 (A1), U4.2 (A1)
/decoding/4 to 16 demux1/SEL2: U3.3 (A2), U4.3 (A2)
/decoding/4 to 16 demux1/SEL3: U3.4 (~E0), U4.6 (E2)
/decoding/~A_EN: U3.5 (~E1), U4.5 (~E1); also elsewhere on the board
/decoding/~A_EN0: U3.15 (~Y0); also elsewhere on the board
/decoding/~A_EN1: U3.14 (~Y1); also elsewhere on the board
/decoding/~A_EN2: U3.13 (~Y2); also elsewhere on the board
/decoding/~A_EN3: U3.12 (~Y3); also elsewhere on the board
/decoding/~A_EN4: U3.11 (~Y4); also elsewhere on the board
/decoding/~A_EN5: U3.10 (~Y5); also elsewhere on the board
/decoding/~A_EN6: U3.9 (~Y6); also elsewhere on the board
/decoding/~A_EN7: U3.7 (~Y7); also elsewhere on the board
/decoding/~A_EN8: U4.15 (~Y0); also elsewhere on the board
/decoding/~A_EN9: U4.14 (~Y1); also elsewhere on the board
/decoding/~A_EN10: U4.13 (~Y2); also elsewhere on the board
/decoding/~A_EN11: U4.12 (~Y3); also elsewhere on the board
/decoding/~A_EN12: U4.11 (~Y4); also elsewhere on the board
/decoding/~A_EN13: U4.10 (~Y5); also elsewhere on the board
/decoding/~A_EN14: U4.9 (~Y6); also elsewhere on the board
/decoding/~A_EN15: U4.7 (~Y7); also elsewhere on the board
GND: C3.2, C4.2, U3.8 (GND), U4.4 (~E0), U4.8 (GND); also elsewhere on the board
VCC: C3.1, C4.1, U3.6 (E2), U3.16 (VCC), U4.16 (VCC); also elsewhere on the board

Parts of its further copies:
C5, C6, C7, C8: 100nF; C_0603_1608Metric
U5, U6, U7, U8: 74HC138; TSSOP-16_L5.0-W4.4-P0.65-LS6.4-BL

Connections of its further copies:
/B_SEL0: U5.1 (A0), U6.1 (A0)
/B_SEL1: U5.2 (A1), U6.2 (A1)
/B_SEL2: U5.3 (A2), U6.3 (A2)
/B_SEL3: U5.4 (~E0), U6.6 (E2)
/CLK: U7.5 (~E1), U8.5 (~E1); also elsewhere on the board
/D_SEL_LATCHED0: U7.1 (A0), U8.1 (A0); also elsewhere on the board
/D_SEL_LATCHED1: U7.2 (A1), U8.2 (A1); also elsewhere on the board
/D_SEL_LATCHED2: U7.3 (A2), U8.3 (A2); also elsewhere on the board
/D_SEL_LATCHED3: U7.4 (~E0), U8.6 (E2); also elsewhere on the board
/LOAD_LATCHED: U7.6 (E2); also elsewhere on the board
/decoding/4 to 16 demux3/~EN2H: U8.4 (~E0); also elsewhere on the board
/decoding/CLK0: U7.15 (~Y0)
/decoding/CLK1: U7.14 (~Y1); also elsewhere on the board
/decoding/CLK2: U7.13 (~Y2); also elsewhere on the board
/decoding/CLK3: U7.12 (~Y3); also elsewhere on the board
/decoding/CLK4: U7.11 (~Y4); also elsewhere on the board
/decoding/CLK5: U7.10 (~Y5); also elsewhere on the board
/decoding/CLK6: U7.9 (~Y6); also elsewhere on the board
/decoding/CLK7: U7.7 (~Y7); also elsewhere on the board
/decoding/CLK8: U8.15 (~Y0); also elsewhere on the board
/decoding/CLK9: U8.14 (~Y1); also elsewhere on the board
/decoding/CLK10: U8.13 (~Y2); also elsewhere on the board
/decoding/CLK11: U8.12 (~Y3); also elsewhere on the board
/decoding/CLK12: U8.11 (~Y4); also elsewhere on the board
/decoding/CLK13: U8.10 (~Y5); also elsewhere on the board
/decoding/CLK14: U8.9 (~Y6); also elsewhere on the board
/decoding/CLK15: U8.7 (~Y7); also elsewhere on the board
/decoding/~B_EN0: U5.15 (~Y0); also elsewhere on the board
/decoding/~B_EN1: U5.14 (~Y1); also elsewhere on the board
/decoding/~B_EN2: U5.13 (~Y2); also elsewhere on the board
/decoding/~B_EN3: U5.12 (~Y3); also elsewhere on the board
/decoding/~B_EN4: U5.11 (~Y4); also elsewhere on the board
/decoding/~B_EN5: U5.10 (~Y5); also elsewhere on the board
/decoding/~B_EN6: U5.9 (~Y6); also elsewhere on the board
/decoding/~B_EN7: U5.7 (~Y7); also elsewhere on the board
/decoding/~B_EN8: U6.15 (~Y0); also elsewhere on the board
/decoding/~B_EN9: U6.14 (~Y1); also elsewhere on the board
/decoding/~B_EN10: U6.13 (~Y2); also elsewhere on the board
/decoding/~B_EN11: U6.12 (~Y3); also elsewhere on the board
/decoding/~B_EN12: U6.11 (~Y4); also elsewhere on the board
/decoding/~B_EN13: U6.10 (~Y5); also elsewhere on the board
/decoding/~B_EN14: U6.9 (~Y6); also elsewhere on the board
/decoding/~B_EN15: U6.7 (~Y7); also elsewhere on the board
/~B_EN: U5.5 (~E1), U6.5 (~E1)
GND: C5.2, C6.2, C7.2, C8.2, U5.8 (GND), U6.4 (~E0), U6.8 (GND), U7.8 (GND), U8.8 (GND); also elsewhere on the board
VCC: C5.1, C6.1, C7.1, C8.1, U5.6 (E2), U5.16 (VCC), U6.16 (VCC), U7.16 (VCC), U8.16 (VCC); also elsewhere on the board

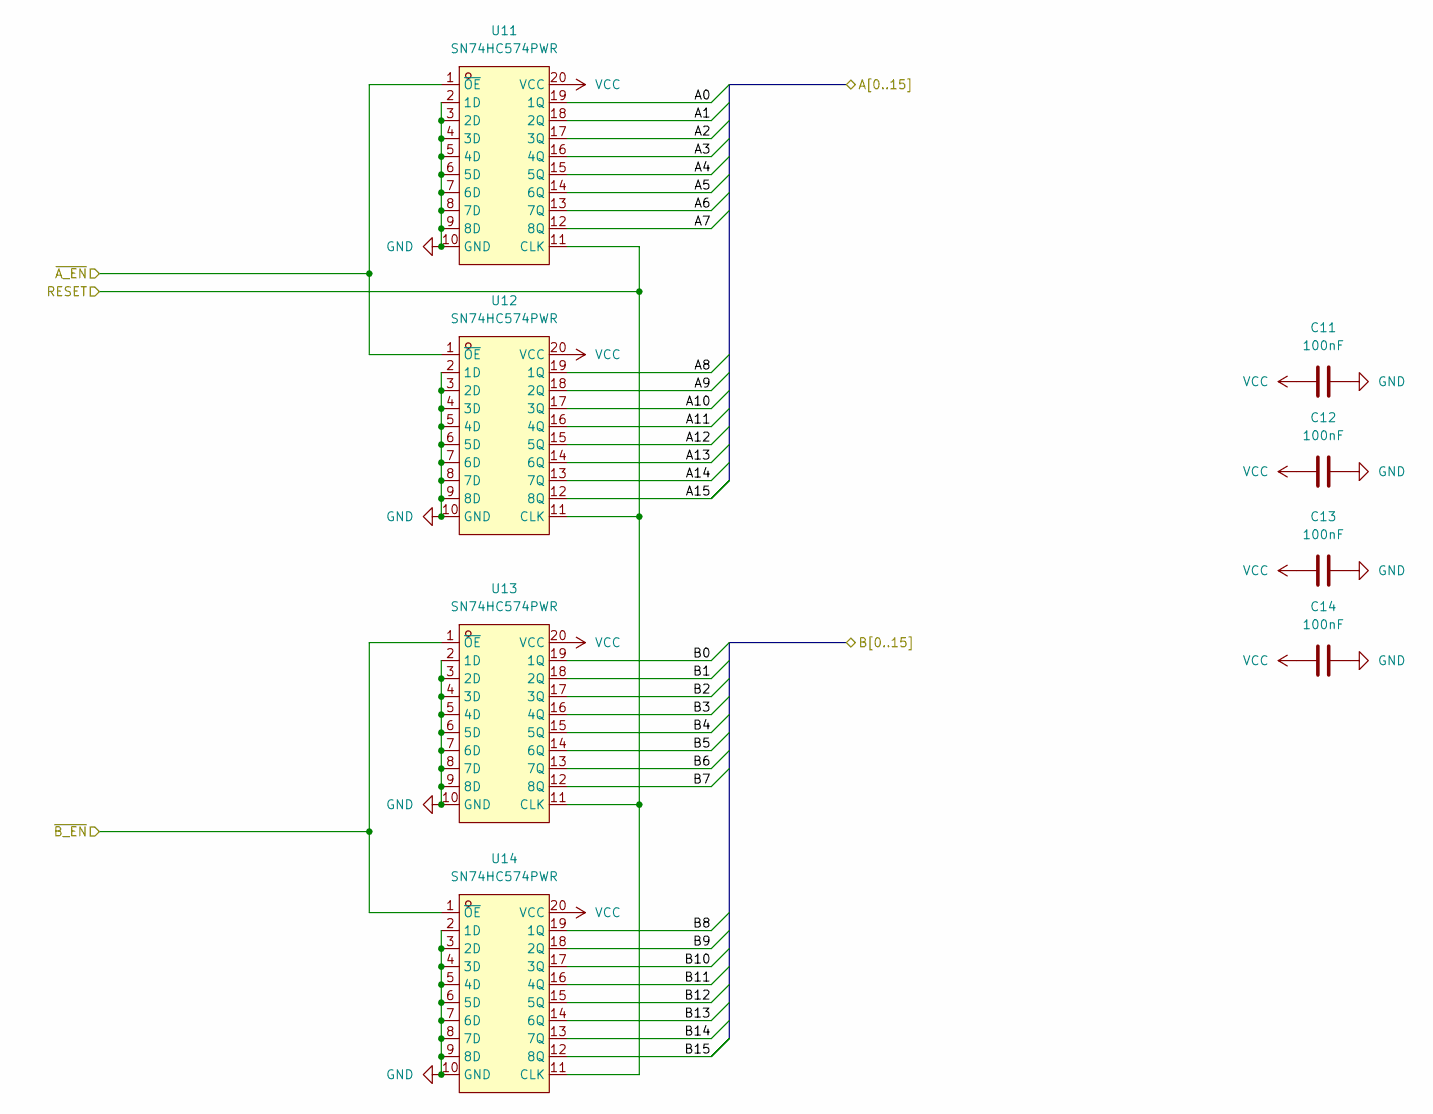
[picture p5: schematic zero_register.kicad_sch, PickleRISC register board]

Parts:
C11, C12, C13, C14: 100nF; C_0603_1608Metric
U11, U12, U13, U14: SN74HC574PWR; TSSOP-20_L6.5-W4.4-P0.65-LS6.4-BL; LCSC Part C132111

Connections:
/A0: U11.19 (1Q); also elsewhere on the board
/A1: U11.18 (2Q); also elsewhere on the board
/A2: U11.17 (3Q); also elsewhere on the board
/A3: U11.16 (4Q); also elsewhere on the board
/A4: U11.15 (5Q); also elsewhere on the board
/A5: U11.14 (6Q); also elsewhere on the board
/A6: U11.13 (7Q); also elsewhere on the board
/A7: U11.12 (8Q); also elsewhere on the board
/A8: U12.19 (1Q); also elsewhere on the board
/A9: U12.18 (2Q); also elsewhere on the board
/A10: U12.17 (3Q); also elsewhere on the board
/A11: U12.16 (4Q); also elsewhere on the board
/A12: U12.15 (5Q); also elsewhere on the board
/A13: U12.14 (6Q); also elsewhere on the board
/A14: U12.13 (7Q); also elsewhere on the board
/A15: U12.12 (8Q); also elsewhere on the board
/B0: U13.19 (1Q); also elsewhere on the board
/B1: U13.18 (2Q); also elsewhere on the board
/B2: U13.17 (3Q); also elsewhere on the board
/B3: U13.16 (4Q); also elsewhere on the board
/B4: U13.15 (5Q); also elsewhere on the board
/B5: U13.14 (6Q); also elsewhere on the board
/B6: U13.13 (7Q); also elsewhere on the board
/B7: U13.12 (8Q); also elsewhere on the board
/B8: U14.19 (1Q); also elsewhere on the board
/B9: U14.18 (2Q); also elsewhere on the board
/B10: U14.17 (3Q); also elsewhere on the board
/B11: U14.16 (4Q); also elsewhere on the board
/B12: U14.15 (5Q); also elsewhere on the board
/B13: U14.14 (6Q); also elsewhere on the board
/B14: U14.13 (7Q); also elsewhere on the board
/B15: U14.12 (8Q); also elsewhere on the board
/RESET: U11.11 (CLK), U12.11 (CLK), U13.11 (CLK), U14.11 (CLK)
/decoding/~A_EN0: U11.1 (~OE), U12.1 (~OE); also elsewhere on the board
/decoding/~B_EN0: U13.1 (~OE), U14.1 (~OE); also elsewhere on the board
GND: C11.2, C12.2, C13.2, C14.2, U11.2 (1D), U11.3 (2D), U11.4 (3D), U11.5 (4D), U11.6 (5D), U11.7 (6D), U11.8 (7D), U11.9 (8D), U11.10 (GND), U12.2 (1D), U12.3 (2D), U12.4 (3D), U12.5 (4D), U12.6 (5D), U12.7 (6D), U12.8 (7D), U12.9 (8D), U12.10 (GND), U13.2 (1D), U13.3 (2D), U13.4 (3D), U13.5 (4D), U13.6 (5D), U13.7 (6D), U13.8 (7D), U13.9 (8D), U13.10 (GND), U14.2 (1D), U14.3 (2D), U14.4 (3D), U14.5 (4D), U14.6 (5D), U14.7 (6D), U14.8 (7D), U14.9 (8D), U14.10 (GND); also elsewhere on the board
VCC: C11.1, C12.1, C13.1, C14.1, U11.20 (VCC), U12.20 (VCC), U13.20 (VCC), U14.20 (VCC); also elsewhere on the board

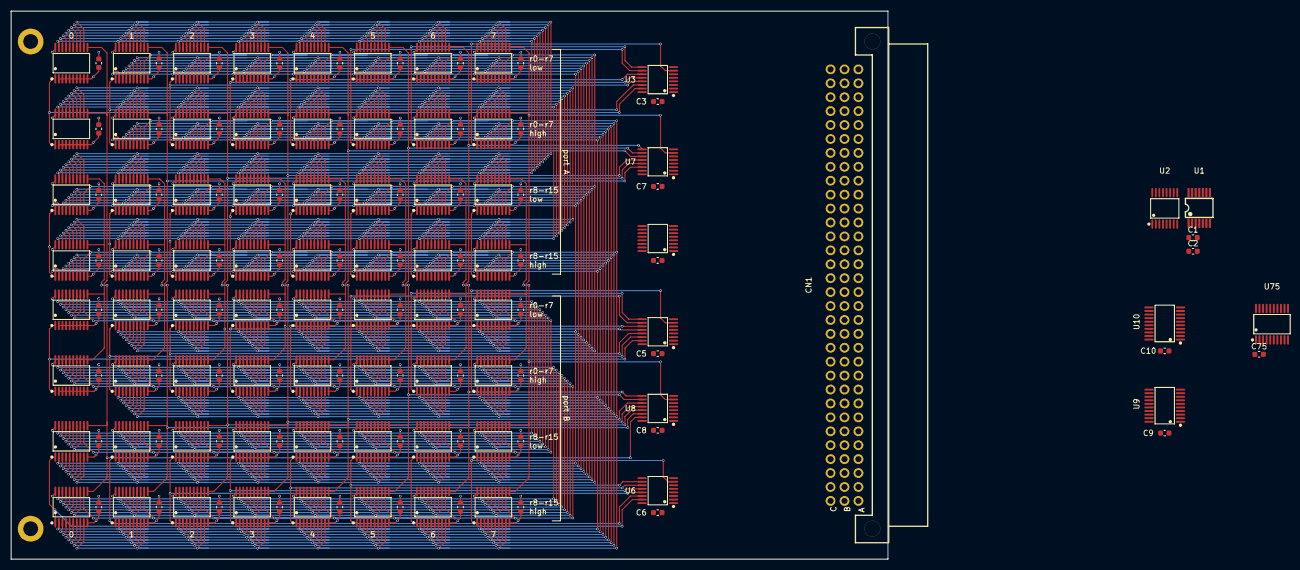
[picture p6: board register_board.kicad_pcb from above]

Board: 4 copper layers, 160.0 x 100.0 mm, 151 parts (0 on the bottom side), 118 nets.

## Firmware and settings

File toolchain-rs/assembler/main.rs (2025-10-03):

mod assembler;
mod chumsky_util;
mod lexer;
mod parser;
mod types;

use ariadne::{Color, Label, Report, ReportKind};
use clap::Parser as _;

use std::{collections::HashMap, fs, io, path::PathBuf};

use crate::{
    assembler::Assembler,
    types::{AssemblerError, FileId, Span},
};

// use assembler::{AsmResult, AssemblerState, files::InputFiles};

#[derive(clap::Parser, Debug)]
struct Cli {
    /// Paths to input assembler files
    input_files: Vec<PathBuf>,

    /// Path to the output file
    #[arg(short, long)]
    output: Option<PathBuf>,
}

#[derive(Debug)]
struct AriadneCache<'assembler> {
    assembler: &'assembler Assembler,
    cache: HashMap<FileId, ariadne::Source<String>>,
    empty_source: ariadne::Source<String>,
}

impl<'assembler> ariadne::Cache<Option<FileId>> for AriadneCache<'assembler> {
    type Storage = String;

    fn fetch(
        &mut self,
        id: &Option<FileId>,
    ) -> Result<&ariadne::Source<Self::Storage>, impl std::fmt::Debug> {
        Ok::<_, io::Error>(if let Some(id) = id {
            match self.cache.entry(*id) {
                std::collections::hash_map::Entry::Occupied(occupied_entry) => {
                    occupied_entry.into_mut()
                }
                std::collections::hash_map::Entry::Vacant(vacant_entry) => {
                    let path = self
                        .assembler
                        .get_path(*id)
                        .expect("It should be impossible to get an invalid FileId");
                    let content = fs::read_to_string(path)?;
                    vacant_entry.insert(content.into())
                }
            }
        } else {
            &self.empty_source
        })
    }

    fn display<'a>(&self, id: &'a Option<FileId>) -> Option<impl std::fmt::Display + 'a> {
        if let Some(id) = id {
            let path = self
                .assembler
                .get_path(*id)
                .expect("It should be impossible to get an invalid FileId");
            Some(format!("{}", path.display()))
        } else {
            Some("<no file>".to_string())
        }
    }
}

impl<'assembler> AriadneCache<'assembler> {
    fn new(assembler: &Assembler) -> AriadneCache<'_> {
        AriadneCache {
            assembler,
            cache: Default::default(),
            empty_source: String::new().into(),
        }
    }
}

impl ariadne::Span for &Span {
    type SourceId = Option<FileId>;

    fn source(&self) -> &Self::SourceId {
        &self.file_id
    }

    fn start(&self) -> usize {
        self.start
    }

    fn end(&self) -> usize {
        self.end
    }
}

fn print_error(error: &'_ AssemblerError) -> ariadne::Report<'_, &'_ Span> {
    match error {
        AssemblerError::InvalidToken(err) | AssemblerError::SyntaxError(err) => {
            let mut report = Report::build(ReportKind::Error, &err.span)
                .with_message(format!(
                    "syntax error: found {}",
                    err.found.as_deref().unwrap_or("end of input")
                ))
                .with_label(
                    Label::new(&err.span)
                        .with_message("error occurred here")
                        .with_color(Color::Red),
                );

            for (ctx, span) in err.context.iter() {
                report = report.with_label(
                    Label::new(span)
                        .with_message(ctx.clone())
                        .with_color(Color::Yellow),
                );
            }

            report
        }

        AssemblerError::NestedMacro {
            span,
            nested_in_name,
            nested_in_span,
        } => Report::build(ReportKind::Error, span)
            .with_message(format!("nested macro inside `{}`", nested_in_name))
            .with_label(
                Label::new(span)
                    .with_message("macro defined here")
                    .with_color(Color::Red),
            )
            .with_label(
                Label::new(nested_in_span)
                    .with_message("enclosing macro")
                    .with_color(Color::Yellow),
            ),

        AssemblerError::FileOpenFailed {
            span,
            file_path,
            error,
        } => Report::build(
            ReportKind::Error,
            span.as_ref().unwrap_or_else(|| &Span {
                file_id: None,
                start: 0,
                end: 0,
            }),
        )
        .with_message(format!(
            "could not open file {}: {}",
            file_path.display(),
            error
        )),
    }
    .finish()
}

fn main() {
    let cli = Cli::parse();

    let mut assembler = Assembler::default();
    let mut errors = Vec::new();

    for file_name in cli.input_files {
        let _ = assembler.add_file(file_name, None, &mut errors);
    }

    if errors.is_empty() {
        dbg!(assembler.assemble());
    }

    let mut sources = AriadneCache::new(&assembler);

    for err in errors {
        print_error(&err).eprint(&mut sources).unwrap();
    }
}

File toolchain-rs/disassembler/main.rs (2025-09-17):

use clap::Parser;
use std::path::PathBuf;
use toolchain_core::image::load_ihex;

use crate::disassembler::Disassembler;

mod disassembler;

#[derive(Parser, Debug)]
struct Cli {
    /// Path to intel hex image of the boot rom
    image_path: PathBuf,
}

fn main() -> anyhow::Result<()> {
    let cli = Cli::parse();

    let img = load_ihex(cli.image_path)?;
    for entry in Disassembler::new(&img) {
        println!("{}", entry);
    }
    Ok(())
}

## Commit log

2019-02-21 Started with assembler
2019-04-17 Incomplete and not working assembler
2019-04-18 ISA WIP:
    - Specified realistic MMU
    - Half done interrupt spec
    - Settled on using microcode, added multi tick instructions
2022-05-20 Simpler and more powerful syscall instruction
2022-06-06 Skeleton of assembler implementation
2022-06-06 assembler: file/line/column location info from tokenization, included in errors
2022-06-06 assembler: add header to error messages
2022-06-06 assembler: Add a preparation step before every pass
2022-06-06 assembler: Parsing numeric literals, primitive version of immediate values
2022-06-07 assembler: Detecting overflow in numeric literals
2022-06-07 assembler: Using a typedef for internal numeric types
2022-06-07 assembler: Separated number parsing and formating for instructions
2022-06-07 assembler: Updated test file with new features
2022-06-07 assembler: Allow underscores in numeric literals
    Same as in python, these are just ignored
2022-06-07 assembler: Don't allow identifiers starting with question mark
2022-06-07 assembler: Refactored tokenizing identifiers into a function
2022-06-07 assembler: Added type-generic stack utility
2022-06-07 assembler: Fix handling of `0`
2022-06-07 assembler: More tokenz!
2022-06-08 assembler: Split main and assembler header
2022-06-10 assembler: Ignoring compile_commands.json
2022-06-10 assembler: Expression parsing
    finished the remaining necessary tokens in tokenizer
2022-06-11 assembler: Fixed assignment instead of comparison
2022-06-12 assembler: Properly working assembler passes and symbol references
    Includes forward references
2022-06-12 assembler: Outputting data in a controlable way.
2022-06-12 assembler: Fail expression parsing when encountering invalid references
2022-06-12 assembler: Support `.db` pseudo-instruction
2022-06-12 assembler: String literals in tokenizer and `.db`
2022-06-12 assembler: `.dw` and `.dd` pseudo-instructions
2022-06-12 assembler: Recursive `.include` directive
2022-06-13 assembler: Sections
2022-06-15 assembler: Warnings as errors for pickle_as build
2022-06-15 assembler: Output to Intel Hex format
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2022-06-16 assembler: Minor formating change
2022-06-16 assembler: Verbose printing of assembled instructions
2022-06-19 assembler: Better and more consistent handling of file errors in tokenizer
2022-06-23 assembler: Reworked tokenizer to use peek instead of unget
2022-07-05 assembler: Refactored Intel Hex functionality from the assembler output adapter
2022-07-05 assembler: Refactored tokenizer -- separated reading file while keeping location
2022-07-05 assembler: Refactored code that will be shared with emulator into a directory
2022-07-05 assembler: Stack of char is now defined centrally
2022-10-06 assembler: Minor (mostly whitespace) tweaks
2022-10-28 emulator: Very minimal emulator main loop, crashes immediately
    [main.rs]
2022-10-28 emulator: Better printing of CPU state
2022-11-02 emulator: Fixed printing of CPU state
2022-11-03 toolchain: Couple tests for instruction structure
2022-11-03 toolchain: Reorganizing the source code to make room for assembler
2022-11-05 assembler: Starting with a lexical analyzer
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2022-11-24 assembler: Lexer EOL changes
    - Separated semicolon and EOL tokens
    - Fixed comment not counting as EOL
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2022-12-04 assembler: Fixed expression parsing bug
    + a few warnings
2022-12-04 assembler: More expression tests, fixing bugs, rustfmt
    [main.rs]
2022-12-04 assembler: Converting tests to use test_case
2022-12-05 assembler: Separated expression parsing to a new file
2022-12-05 assembler: Filling up the gaps in expression parsing tests
2022-12-09 assembler: Fixed missing error propagation
2022-12-11 assembler: Renamed parse state to assembler state
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2022-12-11 assembler: First parser test
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2023-01-16 assembler: Major changes in ASM parser
    - Lexer owns data, rather than borrowing.
    - Changed parser from iterator to slice
    - Refactored assembler state to mod.rs
    - Files DB, compatible with codespan_reporting
2023-04-16 assembler: Getting codespan reporting to work, a bit
2025-09-16 A new fancy 3 operand instruction set
    [instruction_encoding.ods]
2025-09-17 Cutting down the toolchain, start working on the new iteration
    [instruction_encoding.ods]
2025-09-19 Simplifying instruction set to work with pipelined design
    [instruction_encoding.ods]
2025-09-23 First attempts at writing assembly for the platform
    WIP and not tested at alll
2025-09-23 More work on the architecture
    [instruction_encoding.ods]
2025-10-03 Working on the assembler
2025-12-28 Updated block diagram and instruction set
    [instruction_encoding.ods]
2025-12-28 WIP register board in EasyEDA
    This is going to go away soon
2025-12-28 WIP Register board
    Schematic is probably finished, PCB is 75%.
    [16bit_d_flip-flop.kicad_sch, 4_to_16_demux.kicad_sch, decoding.kicad_sch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]
2025-12-29 SystemVerilog model for register board + python tests
2026-01-04 Tweaking the block diagram
    Now includes the split between physical boards
2026-01-06 Formating register board test
2026-01-06 Complex property based test for register board
2026-01-12 Clarifying architecture details around the ALU board
    [instruction_encoding.ods]
2026-01-12 Got rid of LL/SC
    Disabling interrupts in kernel mode will be enough.
    [instruction_encoding.ods]
2026-01-14 ALU board verilog model + testa
2026-01-28 Updated WIP register board PCB
    [register_board.kicad_pcb]
2026-02-03 Thinking through interrupts some more
    [instruction_encoding.ods]
2026-03-21 Couple more notes
    [instruction_encoding.ods]
2026-03-21 Removed DMA master from the block diagram
    Instead we'll have a microcoded multi-cycle memcpy instruction, should be more compact and exactly as fast.
2026-03-21 Added read-only versions of instruction encoding and block diagram
    For viewing in github UI and easier ingestion by Claude
    [instruction_encoding.csv]
2026-03-21 More notes
    [instruction_encoding.csv, instruction_encoding.ods]
